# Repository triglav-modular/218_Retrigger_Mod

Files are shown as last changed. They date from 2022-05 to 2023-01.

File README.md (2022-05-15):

# 218r Retrigger Mod

This is a small add-on PCB that allows for new triggers to be sent from the 218r on each consecutive note without lifting a finger.  It converts the changes in the v/oct output into triggers and adds them to the pulse output. 

There's no need to change any components on the 218r. The "key" and "pulse" inputs just go to the pads above their respective banana jacks. "out" goes directly to the pulse out bananas.
Use a bolt standoff to install it above the STM32.

https://user-images.githubusercontent.com/3920717/165109417-bb7ef8a8-ca0e-416d-88e8-91f72d75c058.mp4

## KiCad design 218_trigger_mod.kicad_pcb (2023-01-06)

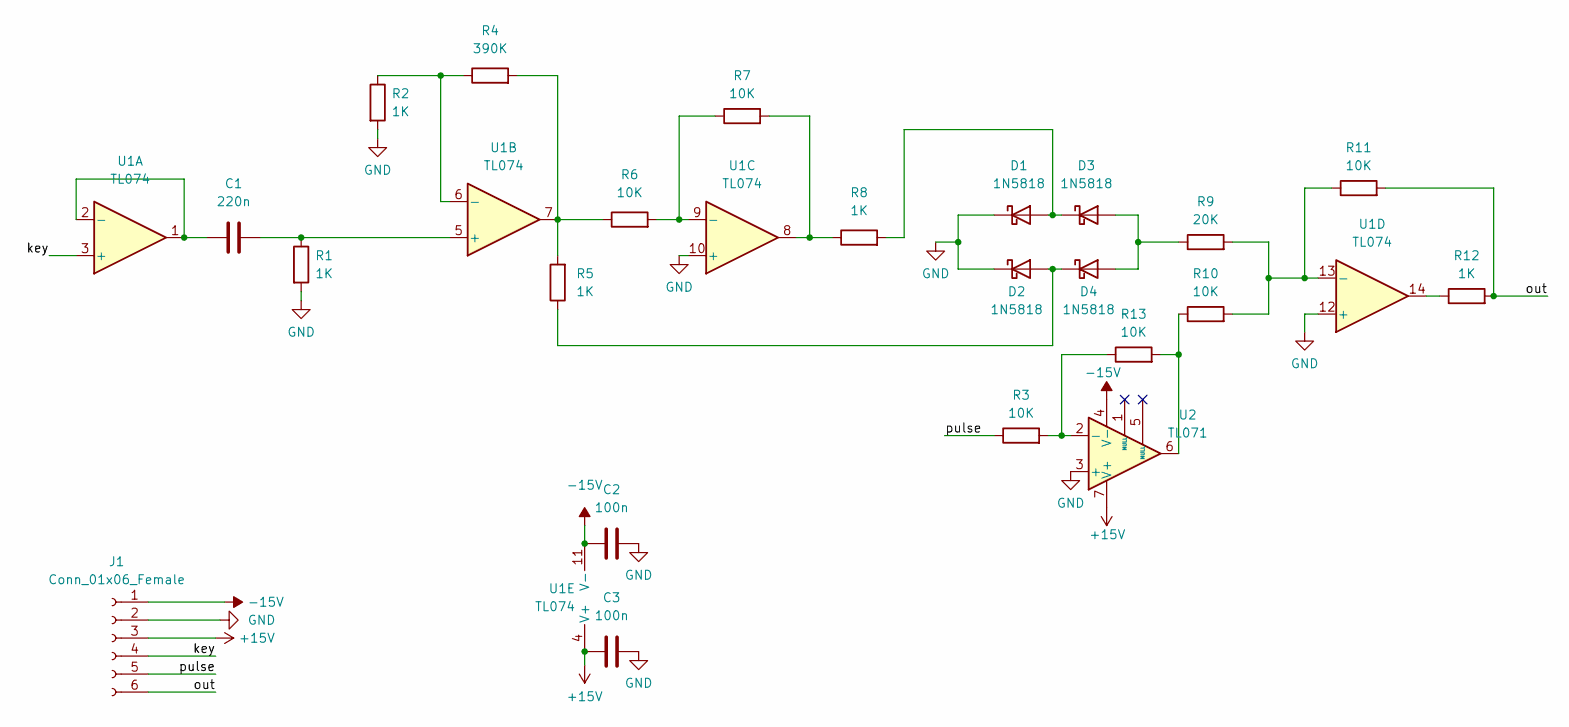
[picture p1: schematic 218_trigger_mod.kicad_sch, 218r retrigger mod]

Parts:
C1: 220n; C_Rect_L7.0mm_W3.5mm_P5.00mm
C2, C3: 100n; C_Rect_L7.0mm_W3.5mm_P5.00mm
D1, D2, D3, D4: 1N5818; D_DO-41_SOD81_P7.62mm_Horizontal
J1: Conn_01x06_Female; PinHeader_1x06_P2.54mm_Vertical
R1, R2, R5, R8, R12: 1K; MusicThingModular-10MM_RESISTOR
R3, R6, R7, R10, R11, R13: 10K; MusicThingModular-10MM_RESISTOR
R4: 390K; MusicThingModular-10MM_RESISTOR
R9: 20K; MusicThingModular-10MM_RESISTOR
U1: TL074; DIP-14_W7.62mm
U2: TL071; DIP-8_W7.62mm

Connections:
+15V: C3.1, J1.3, U1.4 (V+), U2.7 (V+)
-15V: C2.1, J1.1, U1.11 (V-), U2.4 (V-)
/key: J1.4, U1.3 (+)
/out: J1.6, R11.2, R12.2
/pulse: J1.5, R3.1
GND: C2.2, C3.2, D1.1 (K), D2.1 (K), J1.2, R1.2, R2.2, U1.10 (+), U1.12 (+), U2.3 (+)
unnamed: C1.1, U1.1, U1.2 (-)
unnamed: C1.2, R1.1, U1.5 (+)
unnamed: D1.2 (A), D3.1 (K), R8.2
unnamed: D2.2 (A), D4.1 (K), R5.1
unnamed: D3.2 (A), D4.2 (A), R9.1
unnamed: R2.1, R4.1, U1.6 (-)
unnamed: R4.2, R5.2, R6.1, U1.7
unnamed: R6.2, R7.1, U1.9 (-)
unnamed: R7.2, R8.1, U1.8
unnamed: R10.1, R13.2, U2.6
unnamed: R9.2, R10.2, R11.1, U1.13 (-)
unnamed: R12.1, U1.14
unnamed: R3.2, R13.1, U2.2 (-)

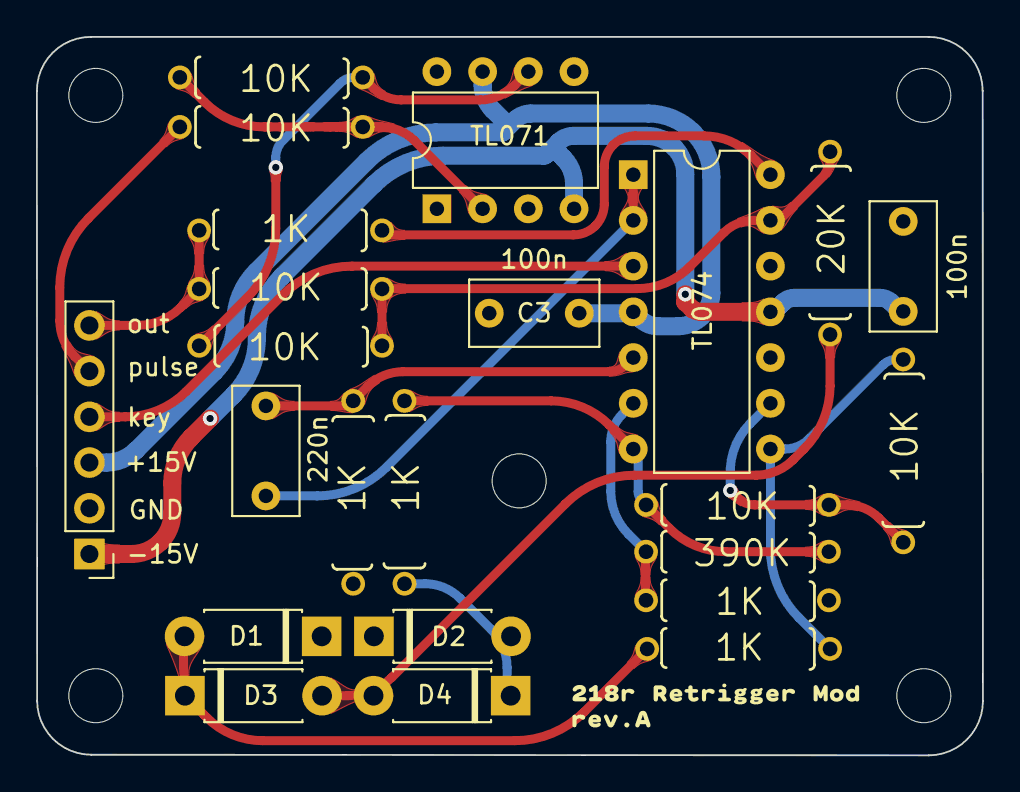
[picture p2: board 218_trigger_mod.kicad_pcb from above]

Board: 2 copper layers, 52.6 x 39.9 mm, 25 parts (0 on the bottom side), 19 nets.

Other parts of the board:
kibuzzard-62811A1C: G***; kibuzzard-62811A1C
kibuzzard-62811A51: G***; kibuzzard-62811A51
